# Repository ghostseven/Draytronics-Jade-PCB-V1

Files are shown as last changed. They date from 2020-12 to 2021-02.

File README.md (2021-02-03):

# Draytronics-Jade-PCB-V1

## Currently untested pre-production only.

jade  

An open source 65% mechanical keyboard, designed to be easily built with through hole components. More info / kits / PCB designs available at https://www.draytronics.co.uk/jade

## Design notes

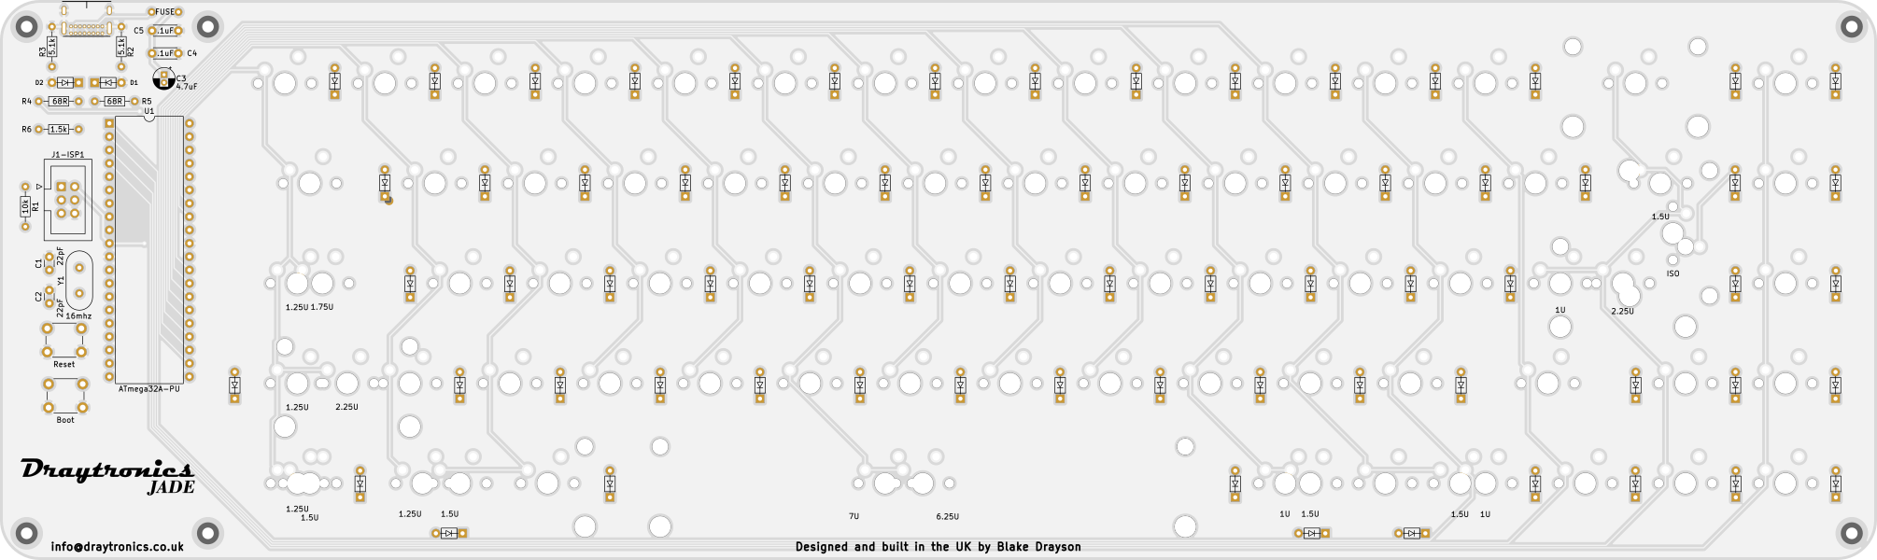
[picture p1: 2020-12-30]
Draytronics-Jade-V1.png

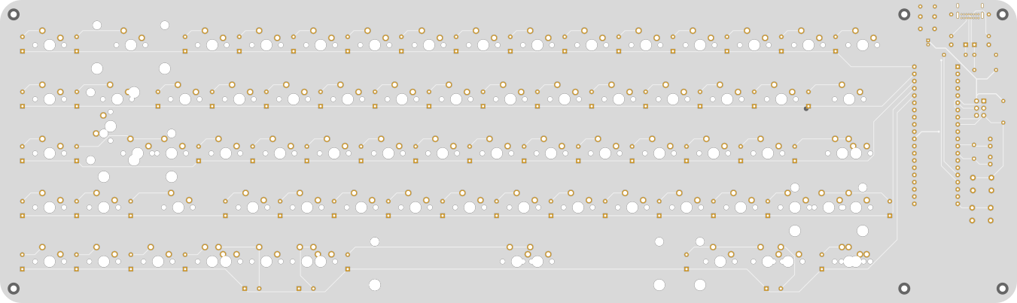
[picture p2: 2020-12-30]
Draytronics-Jade-V1-bottom.png

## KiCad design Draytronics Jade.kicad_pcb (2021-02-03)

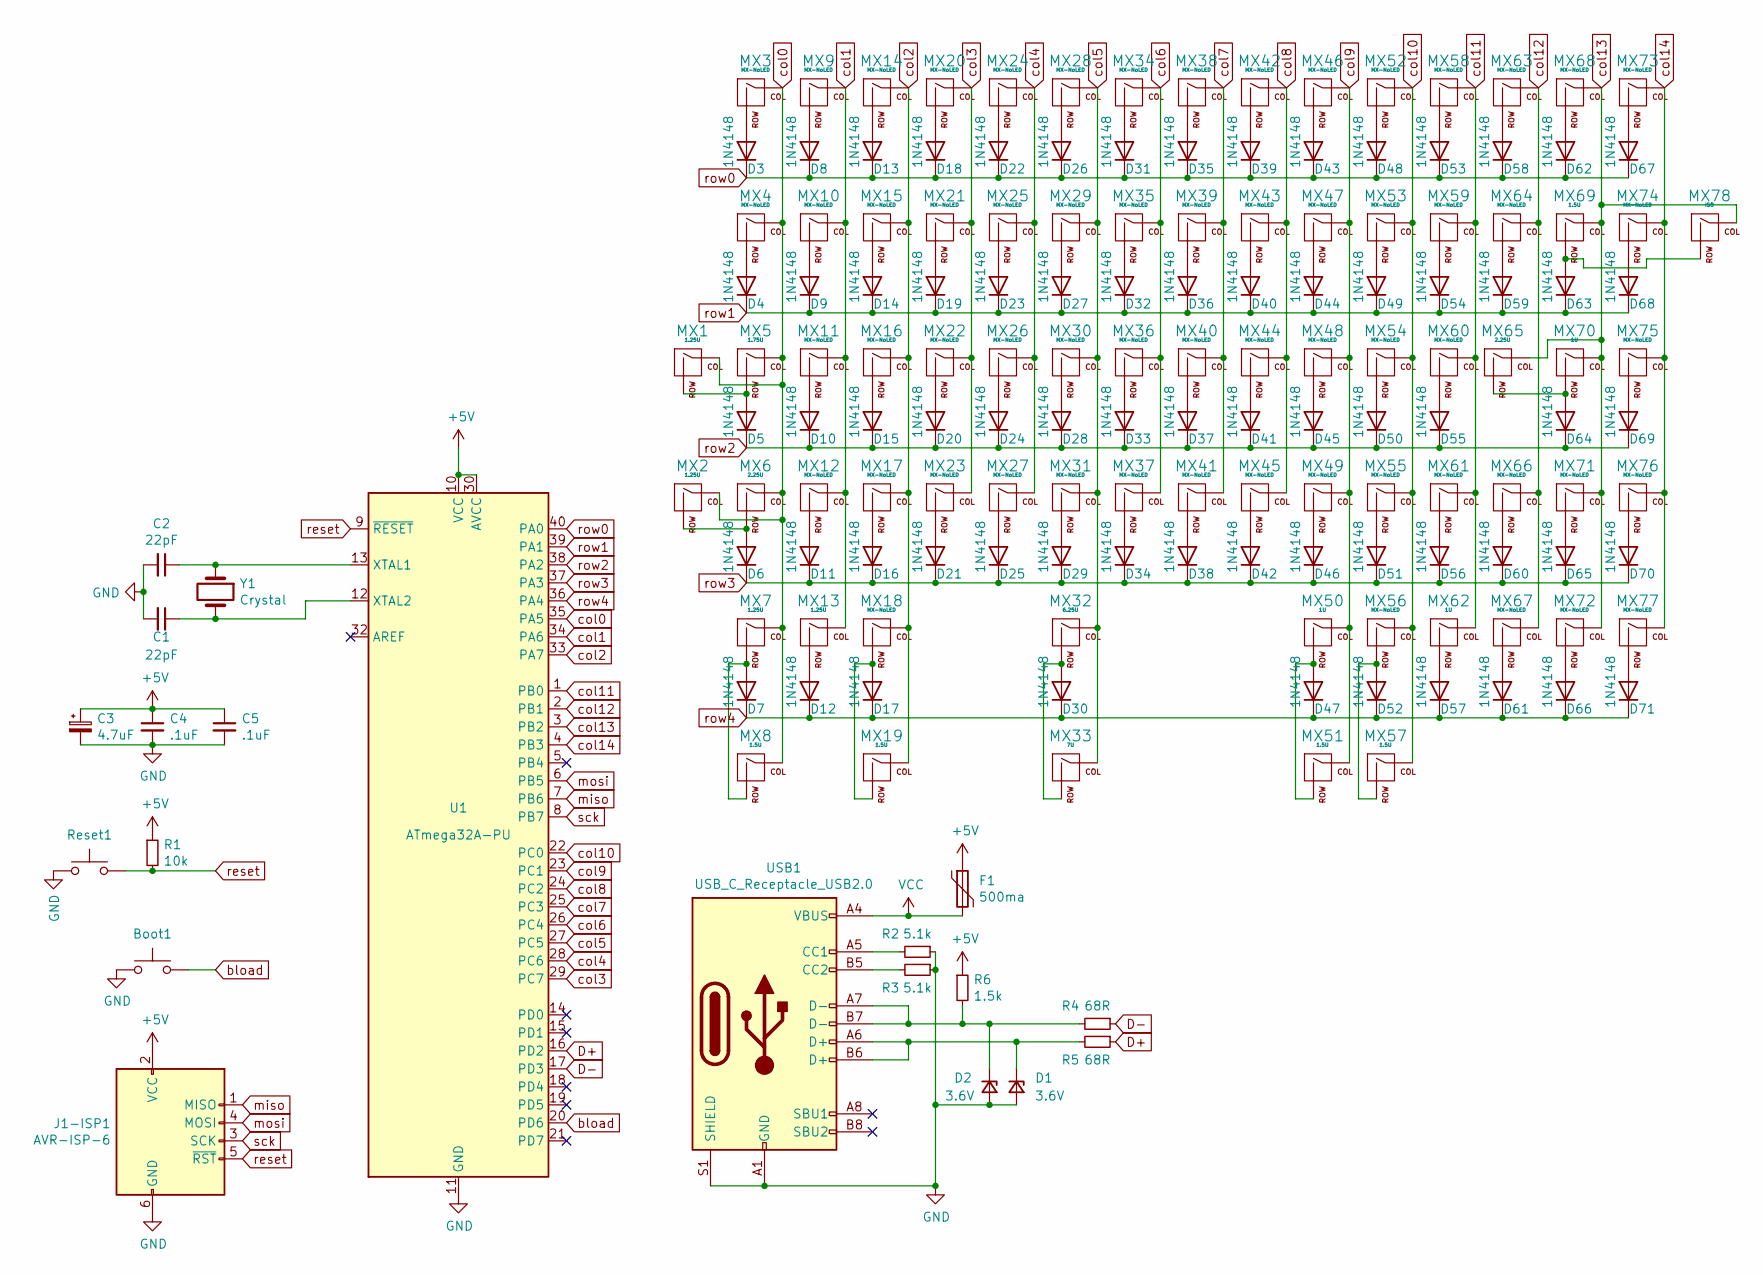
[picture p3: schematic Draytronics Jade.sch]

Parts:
Boot1: Boot; SW_PUSH_6mm
C1, C2: 22pF; C_Disc_D3.0mm_W1.6mm_P2.50mm
C3: 4.7uF; CP_Radial_D4.0mm_P1.50mm
C4, C5: .1uF; C_Disc_D4.3mm_W1.9mm_P5.00mm
D1, D2: 3.6V; D_DO-35_SOD27_P5.08mm_Horizontal
D3, D4, D5, D6, D7, D8, D9, D10, D11, D12, D13, D14, D15, D16, D17, D18, D19, D20, D21, D22, D23, D24, D25, D26, D27, D28, D29, D30, D31, D32, D33, D34, D35, D36, D37, D38, D39, D40, D41, D42, D43, D44, D45, D46, D47, D48, D49, D50, D51, D52, D53, D54, D55, D56, D57, D58, D59, D60, D61, D62, D63, D64, D65, D66, D67, D68, D69, D70, D71: 1N4148; D_DO-35_SOD27_P5.08mm_Horizontal
F1: 500ma; polyfuse_5.1mm
J1-ISP1: AVR-ISP-6; IDC-Header_2x03_P2.54mm_Vertical
MX1, MX2, MX7, MX13: 1.25U; MXOnly-1.25U-NoLED
MX3, MX9, MX10, MX11, MX12, MX14, MX15, MX16, MX17, MX20, MX21, MX22, MX23, MX24, MX25, MX26, MX27, MX28, MX29, MX30, MX31, MX34, MX35, MX36, MX37, MX38, MX39, MX40, MX41, MX42, MX43, MX44, MX45, MX46, MX47, MX48, MX49, MX52, MX53, MX54, MX55, MX56, MX58, MX59, MX60, MX61, MX63, MX64, MX67, MX71, MX72, MX73, MX74, MX75, MX76, MX77: MX-NoLED; MXOnly-1U-NoLED
MX4: MX-NoLED; MXOnly-1.5U-NoLED
MX5: 1.75U; MXOnly-1.75U-NoLED
MX6, MX65: 2.25U; MXOnly-2.25U-NoLED
MX8, MX19, MX51, MX57, MX69: 1.5U; MXOnly-1.5U-NoLED
MX18: MX-NoLED; MXOnly-1.25U-NoLED
MX32: 6.25U; MXOnly-6.25U-NoLED
MX33: 7U; MXOnly-7U-NoLED
MX50, MX62, MX70: 1U; MXOnly-1U-NoLED
MX66: MX-NoLED; MXOnly-1.75U-NoLED
MX68: MX-NoLED; MXOnly-2U-NoLED
MX78: ISO; MXOnly-ISO-ROTATED-ReversedStabilizers-NoLED
R1: 10k; R_Axial_DIN0204_L3.6mm_D1.6mm_P7.62mm_Horizontal
R2, R3: 5.1k; R_Axial_DIN0204_L3.6mm_D1.6mm_P7.62mm_Horizontal
R4, R5: 68R; R_Axial_DIN0204_L3.6mm_D1.6mm_P7.62mm_Horizontal
R6: 1.5k; R_Axial_DIN0204_L3.6mm_D1.6mm_P7.62mm_Horizontal
Reset1: Reset; SW_PUSH_6mm
U1: ATmega32A-PU; DIP-40_W15.24mm
USB1: USB_C_Receptacle_USB2.0; USB_C_GCT_USB4085
Y1: Crystal; Crystal_HC49-U_Vertical

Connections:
+5V: C3.1, C4.1, C5.1, F1.1, J1-ISP1.2 (VCC), R1.1, R6.1, U1.10 (VCC), U1.30 (AVCC)
D+: R5.1, U1.16 (PD2)
D-: R4.1, U1.17 (PD3)
GND: Boot1.1, C1.2, C2.2, C3.2, C4.2, C5.2, D1.2 (A), D2.2 (A), J1-ISP1.6 (GND), R2.1, R3.1, Reset1.1, U1.11 (GND), U1.31 (GND), USB1.A1 (GND), USB1.A12 (GND), USB1.B1 (GND), USB1.B12 (GND), USB1.S1 (SHIELD)
unnamed: C1.1, U1.12 (XTAL2), Y1.2
unnamed: C2.1, U1.13 (XTAL1), Y1.1
unnamed: D1.1 (K), R5.2, USB1.A6 (D+), USB1.B6 (D+)
unnamed: D2.1 (K), R4.2, R6.2, USB1.A7 (D-), USB1.B7 (D-)
unnamed: D3.2 (A), MX3.2 (ROW)
unnamed: D4.2 (A), MX4.2 (ROW)
unnamed: D5.2 (A), MX1.2 (ROW), MX5.2 (ROW)
unnamed: D6.2 (A), MX2.2 (ROW), MX6.2 (ROW)
unnamed: D7.2 (A), MX7.2 (ROW), MX8.2 (ROW)
unnamed: D8.2 (A), MX9.2 (ROW)
unnamed: D9.2 (A), MX10.2 (ROW)
unnamed: D10.2 (A), MX11.2 (ROW)
unnamed: D11.2 (A), MX12.2 (ROW)
unnamed: D12.2 (A), MX13.2 (ROW)
unnamed: D13.2 (A), MX14.2 (ROW)
unnamed: D14.2 (A), MX15.2 (ROW)
unnamed: D15.2 (A), MX16.2 (ROW)
unnamed: D16.2 (A), MX17.2 (ROW)
unnamed: D17.2 (A), MX18.2 (ROW), MX19.2 (ROW)
unnamed: D18.2 (A), MX20.2 (ROW)
unnamed: D19.2 (A), MX21.2 (ROW)
unnamed: D20.2 (A), MX22.2 (ROW)
unnamed: D21.2 (A), MX23.2 (ROW)
unnamed: D22.2 (A), MX24.2 (ROW)
unnamed: D23.2 (A), MX25.2 (ROW)
unnamed: D24.2 (A), MX26.2 (ROW)
unnamed: D25.2 (A), MX27.2 (ROW)
unnamed: D26.2 (A), MX28.2 (ROW)
unnamed: D27.2 (A), MX29.2 (ROW)
unnamed: D28.2 (A), MX30.2 (ROW)
unnamed: D29.2 (A), MX31.2 (ROW)
unnamed: D30.2 (A), MX32.2 (ROW), MX33.2 (ROW)
unnamed: D31.2 (A), MX34.2 (ROW)
unnamed: D32.2 (A), MX35.2 (ROW)
unnamed: D33.2 (A), MX36.2 (ROW)
unnamed: D34.2 (A), MX37.2 (ROW)
unnamed: D35.2 (A), MX38.2 (ROW)
unnamed: D36.2 (A), MX39.2 (ROW)
unnamed: D37.2 (A), MX40.2 (ROW)
unnamed: D38.2 (A), MX41.2 (ROW)
unnamed: D39.2 (A), MX42.2 (ROW)
unnamed: D40.2 (A), MX43.2 (ROW)
unnamed: D41.2 (A), MX44.2 (ROW)
unnamed: D42.2 (A), MX45.2 (ROW)
unnamed: D43.2 (A), MX46.2 (ROW)
unnamed: D44.2 (A), MX47.2 (ROW)
unnamed: D45.2 (A), MX48.2 (ROW)
unnamed: D46.2 (A), MX49.2 (ROW)
unnamed: D47.2 (A), MX50.2 (ROW), MX51.2 (ROW)
unnamed: D48.2 (A), MX52.2 (ROW)
unnamed: D49.2 (A), MX53.2 (ROW)
unnamed: D50.2 (A), MX54.2 (ROW)
unnamed: D51.2 (A), MX55.2 (ROW)
unnamed: D52.2 (A), MX56.2 (ROW), MX57.2 (ROW)
unnamed: D53.2 (A), MX58.2 (ROW)
unnamed: D54.2 (A), MX59.2 (ROW)
unnamed: D55.2 (A), MX60.2 (ROW)
unnamed: D56.2 (A), MX61.2 (ROW)
unnamed: D57.2 (A), MX62.2 (ROW)
unnamed: D58.2 (A), MX63.2 (ROW)
unnamed: D59.2 (A), MX64.2 (ROW)
unnamed: D60.2 (A), MX66.2 (ROW)
unnamed: D61.2 (A), MX67.2 (ROW)
unnamed: D62.2 (A), MX68.2 (ROW)
unnamed: D63.2 (A), MX69.2 (ROW), MX78.2 (ROW)
unnamed: D64.2 (A), MX65.2 (ROW), MX70.2 (ROW)
unnamed: D65.2 (A), MX71.2 (ROW)
unnamed: D66.2 (A), MX72.2 (ROW)
unnamed: D67.2 (A), MX73.2 (ROW)
unnamed: D68.2 (A), MX74.2 (ROW)
unnamed: D69.2 (A), MX75.2 (ROW)
unnamed: D70.2 (A), MX76.2 (ROW)
unnamed: D71.2 (A), MX77.2 (ROW)
unnamed: R2.2, USB1.A5 (CC1)
unnamed: R3.2, USB1.B5 (CC2)
VCC: F1.2, USB1.A4 (VBUS), USB1.A9 (VBUS), USB1.B4 (VBUS), USB1.B9 (VBUS)
bload: Boot1.2, U1.20 (PD6)
col0: MX1.1 (COL), MX2.1 (COL), MX3.1 (COL), MX4.1 (COL), MX5.1 (COL), MX6.1 (COL), MX7.1 (COL), MX8.1 (COL), U1.35 (PA5)
col1: MX9.1 (COL), MX10.1 (COL), MX11.1 (COL), MX12.1 (COL), MX13.1 (COL), U1.34 (PA6)
col2: MX14.1 (COL), MX15.1 (COL), MX16.1 (COL), MX17.1 (COL), MX18.1 (COL), MX19.1 (COL), U1.33 (PA7)
col3: MX20.1 (COL), MX21.1 (COL), MX22.1 (COL), MX23.1 (COL), U1.29 (PC7)
col4: MX24.1 (COL), MX25.1 (COL), MX26.1 (COL), MX27.1 (COL), U1.28 (PC6)
col5: MX28.1 (COL), MX29.1 (COL), MX30.1 (COL), MX31.1 (COL), MX32.1 (COL), MX33.1 (COL), U1.27 (PC5)
col6: MX34.1 (COL), MX35.1 (COL), MX36.1 (COL), MX37.1 (COL), U1.26 (PC4)
col7: MX38.1 (COL), MX39.1 (COL), MX40.1 (COL), MX41.1 (COL), U1.25 (PC3)
col8: MX42.1 (COL), MX43.1 (COL), MX44.1 (COL), MX45.1 (COL), U1.24 (PC2)
col9: MX46.1 (COL), MX47.1 (COL), MX48.1 (COL), MX49.1 (COL), MX50.1 (COL), MX51.1 (COL), U1.23 (PC1)
col10: MX52.1 (COL), MX53.1 (COL), MX54.1 (COL), MX55.1 (COL), MX56.1 (COL), MX57.1 (COL), U1.22 (PC0)
col11: MX58.1 (COL), MX59.1 (COL), MX60.1 (COL), MX61.1 (COL), MX62.1 (COL), U1.1 (PB0)
col12: MX63.1 (COL), MX64.1 (COL), MX66.1 (COL), MX67.1 (COL), U1.2 (PB1)
col13: MX65.1 (COL), MX68.1 (COL), MX69.1 (COL), MX70.1 (COL), MX71.1 (COL), MX72.1 (COL), MX78.1 (COL), U1.3 (PB2)
col14: MX73.1 (COL), MX74.1 (COL), MX75.1 (COL), MX76.1 (COL), MX77.1 (COL), U1.4 (PB3)
miso: J1-ISP1.1 (MISO), U1.7 (PB6)
mosi: J1-ISP1.4 (MOSI), U1.6 (PB5)
reset: J1-ISP1.5 (~RST), R1.2, Reset1.2, U1.9 (~RESET)
row0: D3.1 (K), D8.1 (K), D13.1 (K), D18.1 (K), D22.1 (K), D26.1 (K), D31.1 (K), D35.1 (K), D39.1 (K), D43.1 (K), D48.1 (K), D53.1 (K), D58.1 (K), D62.1 (K), D67.1 (K), U1.40 (PA0)
row1: D4.1 (K), D9.1 (K), D14.1 (K), D19.1 (K), D23.1 (K), D27.1 (K), D32.1 (K), D36.1 (K), D40.1 (K), D44.1 (K), D49.1 (K), D54.1 (K), D59.1 (K), D63.1 (K), D68.1 (K), U1.39 (PA1)
row2: D5.1 (K), D10.1 (K), D15.1 (K), D20.1 (K), D24.1 (K), D28.1 (K), D33.1 (K), D37.1 (K), D41.1 (K), D45.1 (K), D50.1 (K), D55.1 (K), D64.1 (K), D69.1 (K), U1.38 (PA2)
row3: D6.1 (K), D11.1 (K), D16.1 (K), D21.1 (K), D25.1 (K), D29.1 (K), D34.1 (K), D38.1 (K), D42.1 (K), D46.1 (K), D51.1 (K), D56.1 (K), D60.1 (K), D65.1 (K), D70.1 (K), U1.37 (PA3)
row4: D7.1 (K), D12.1 (K), D17.1 (K), D30.1 (K), D47.1 (K), D52.1 (K), D57.1 (K), D61.1 (K), D66.1 (K), D71.1 (K), U1.36 (PA4)
sck: J1-ISP1.3 (SCK), U1.8 (PB7)

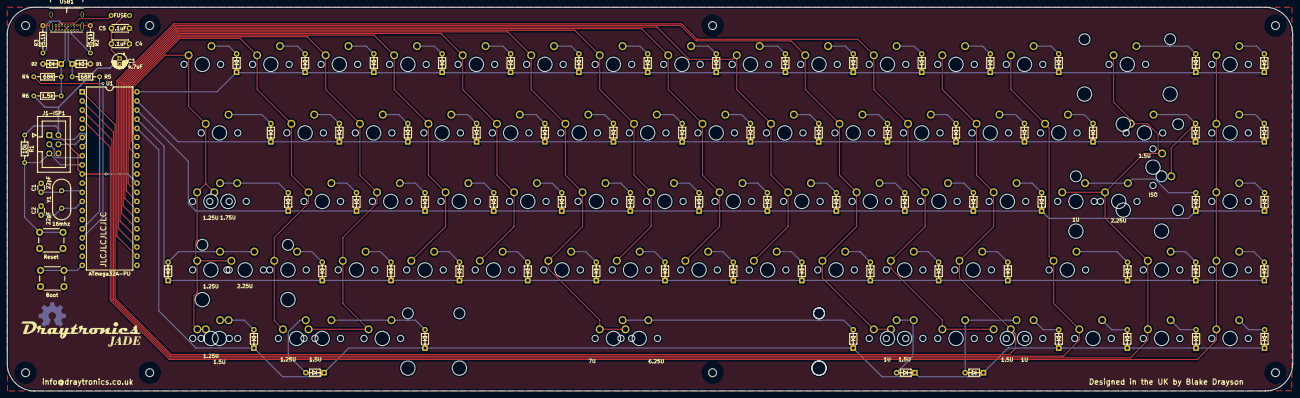
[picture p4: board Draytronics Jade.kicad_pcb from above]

Board: 2 copper layers, 357.4 x 106.7 mm, 167 parts (0 on the bottom side), 105 nets.

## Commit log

2020-12-30 Added PCB renders
2021-02-03 Added middle standoff for stability
    [Draytronics Jade-B_Cu.gbl, Draytronics Jade-B_Mask.gbs, Draytronics Jade-B_Paste.gbp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]
